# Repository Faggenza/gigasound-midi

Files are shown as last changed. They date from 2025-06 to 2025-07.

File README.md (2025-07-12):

# Gigasound MIDI Polyphonic Keyboard

A USB-connected MPE MIDI keyboard using piezoresistive sensors for expressive, pressure-sensitive input, built around the STM32F401 microcontroller.

Case

## Source Tree

```
├── sprite/     # Assets in aseprite format
├── assets_src/ # Assets in bitmap format 
├── convert_asset.py # Asset convertion tool
├── emulator/
│   ├── emulator.h
│   └── Makefile
├── gigasound-hw/ # PCB KiCad files
├── include/
│   ├── adc.h
│   ├── assets.h
│   ├── bootloader.h
│   ├── calibrate.h
│   ├── config.h
│   ├── eeprom.h
│   ├── init.h
│   ├── input.h
│   ├── led.h
│   ├── main.h
│   ├── midi.h
│   ├── scale.h
│   ├── ssd1306.h
│   ├── stm32f4xx_it.h
│   ├── tusb_config.h
│   ├── uart.h
│   └── ui/
├── lib
│   └── gigagl # embedded graphics library
├── platformio.ini 
└── src/
    ├── adc.c
    ├── assets
    ├── calibrate.c
    ├── config.c
    ├── eeprom.c
    ├── init.c
    ├── input.c
    ├── led.c
    ├── main.c
    ├── midi.c
    ├── scale.c
    ├── stm32f4xx_hal_msp.c
    ├── stm32f4xx_it.c
    ├── uart.c
    ├── ui/               
    └── usb_descriptors.c
```

## References

MCU: [STM32F0401RE](https://www.st.com/resource/en/datasheet/stm32f401re.pdf)

Nucleo: [Schematic](https://www.st.com/resource/en/schematic_pack/mb1136-default-c04_schematic.pdf)

Piezoresistive sensor: [datasheet](https://cdn2.hubspot.net/hubfs/3899023/Interlinkelectronics%20November2017/Docs/Datasheet_FSR.pdf)

MIDI: [docs](https://drive.google.com/file/d/1QGjiK2QPPbii8YmES3vDEZlP63OGLiKr/view)

## Testing

[MPE Monitor](https://studiocode.dev/mpe-monitor/)

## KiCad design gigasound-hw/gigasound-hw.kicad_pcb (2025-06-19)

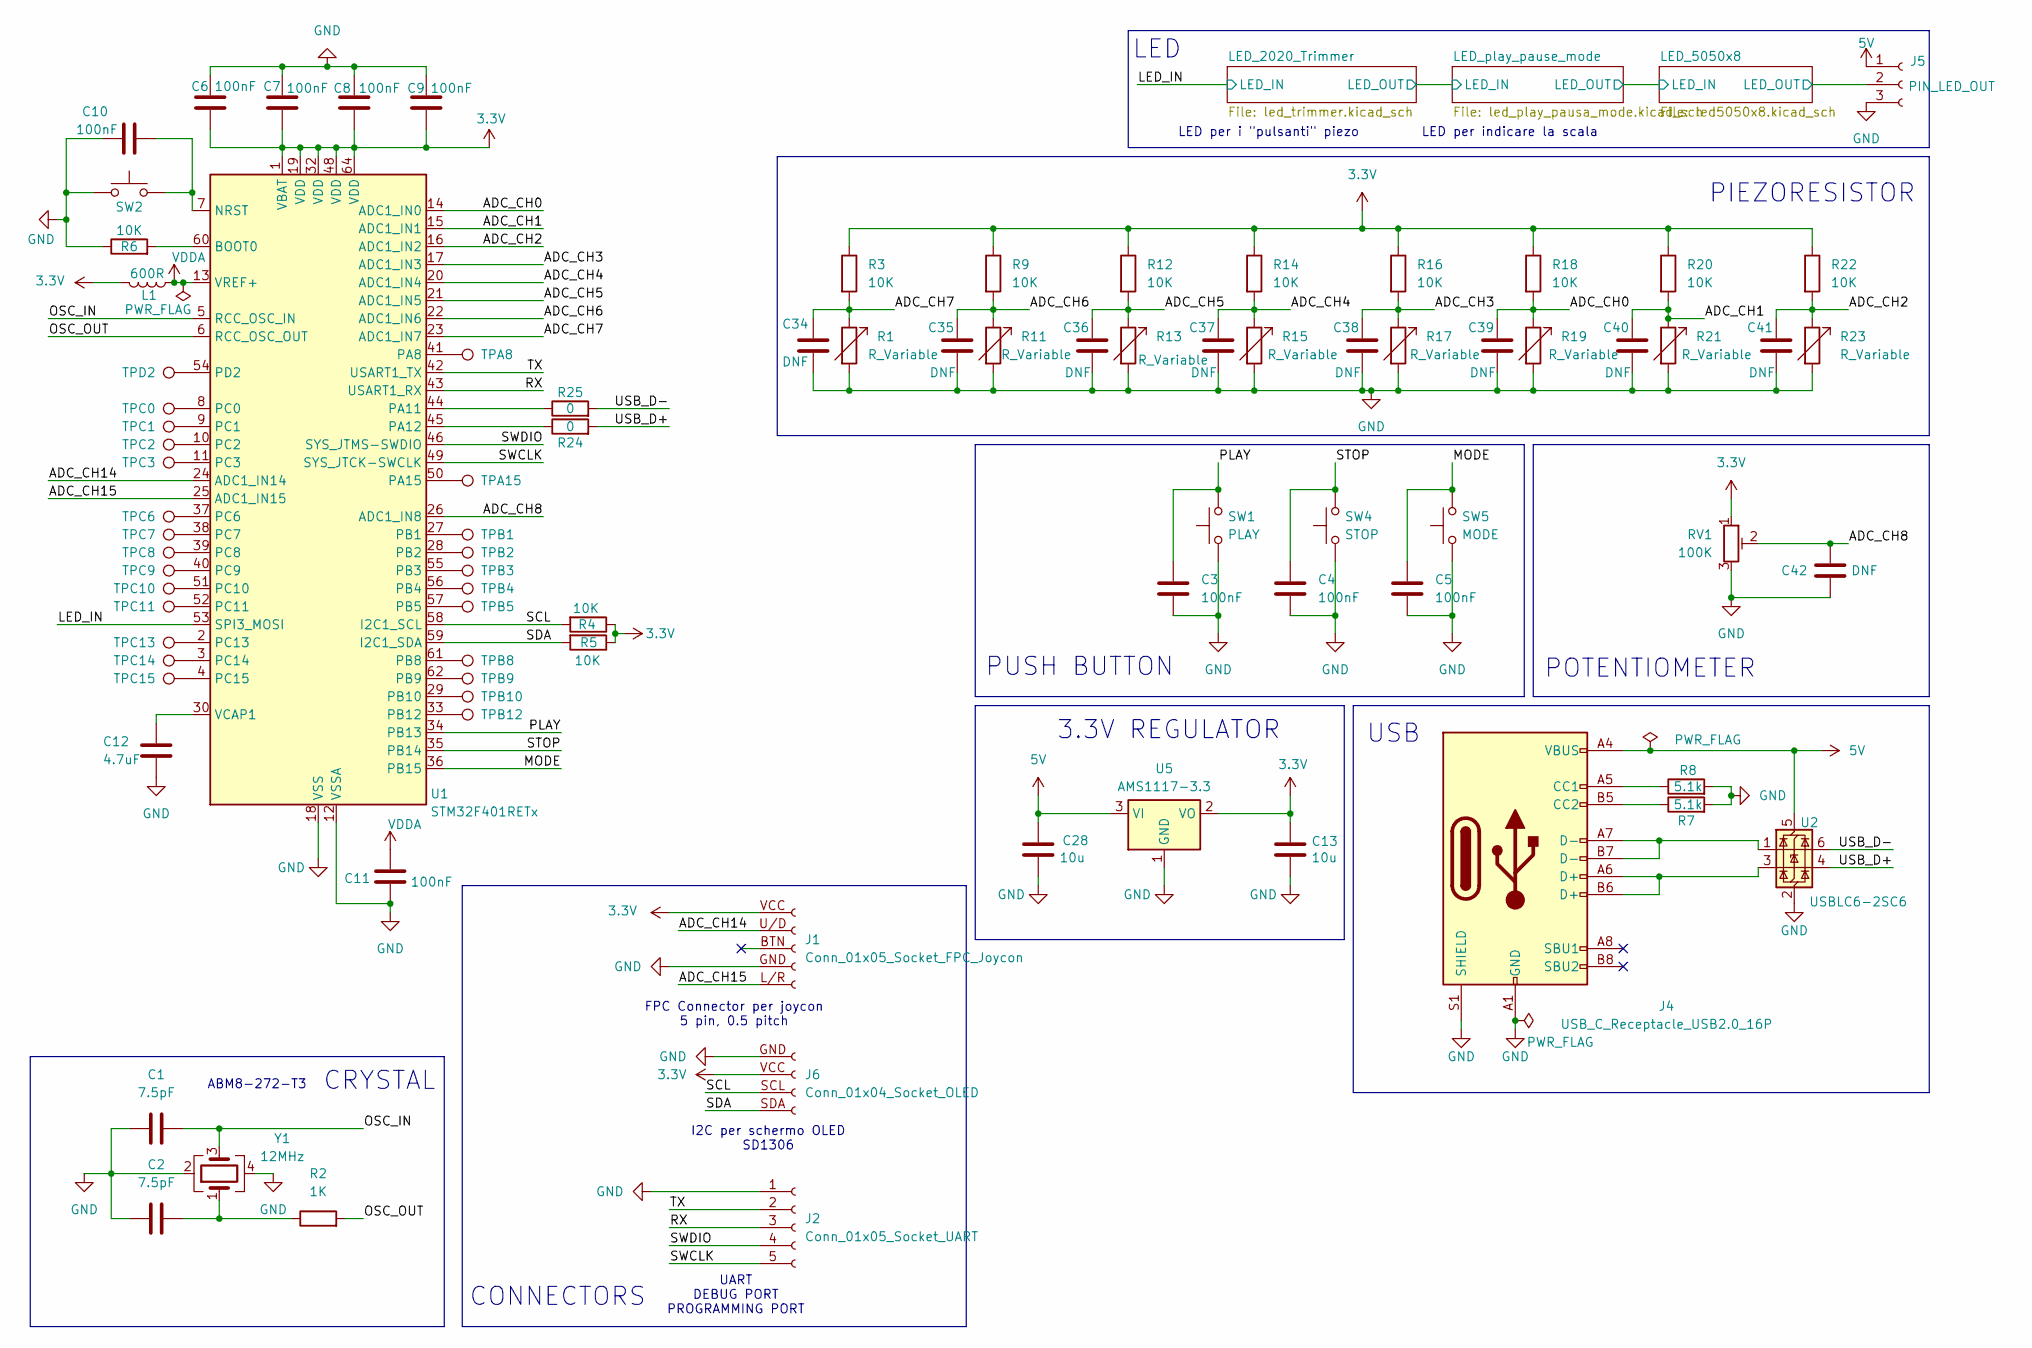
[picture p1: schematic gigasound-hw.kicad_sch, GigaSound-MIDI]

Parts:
C1, C2: 7.5pF; C_0402_1005Metric_Pad0.74x0.62mm_HandSolder
C3, C4, C5, C6, C7, C8, C9, C10, C11: 100nF; C_0402_1005Metric_Pad0.74x0.62mm_HandSolder
C12: 4.7uF; C_0805_2012Metric_Pad1.18x1.45mm_HandSolder
C13, C28: 10u; C_0805_2012Metric_Pad1.18x1.45mm_HandSolder
C34, C35, C36, C37, C38, C39, C40, C41, C42: DNF; C_0402_1005Metric_Pad0.74x0.62mm_HandSolder
J1: Conn_01x05_Socket_FPC_Joycon; Joycon-FPC-1x05-P0.5mm
J2: Conn_01x05_Socket_UART; PinHeader_1x05_P2.54mm_Vertical
J4: USB_C_Receptacle_USB2.0_16P; USB_C_Receptacle_G-Switch_GT-USB-7010ASV
J5: PIN_LED_OUT; PinHeader_1x03_P2.54mm_Vertical
J6: Conn_01x04_Socket_OLED; PinSocket_1x04_P2.54mm_Vertical_OLED_0.96inch
L1: 600R; L_0201_0603Metric_Pad0.64x0.40mm_HandSolder
R1, R11, R13, R15, R17, R19, R21, R23: R_Variable; FSR402
R2: 1K; R_0402_1005Metric_Pad0.72x0.64mm_HandSolder
R3, R4, R5, R6, R9, R12, R14, R16, R18, R20, R22: 10K; R_0402_1005Metric_Pad0.72x0.64mm_HandSolder
R7, R8: 5.1k; R_0402_1005Metric_Pad0.72x0.64mm_HandSolder
R24, R25: 0; R_0402_1005Metric_Pad0.72x0.64mm_HandSolder
RV1: 100K; Potentiometer_Alps_RK09K_Single_Vertical
SW1: PLAY; SW_SPST_TL3342
SW2: Reset; SW_Push_SPST_NO_Alps_SKRK
SW4: STOP; SW_SPST_TL3342
SW5: MODE; SW_SPST_TL3342
TPA8, TPA15: TestPoint_Pad_D1.0mm
TPB1, TPB2, TPB3, TPB4, TPB5, TPB8, TPB9, TPB10, TPB12: TestPoint_Pad_D1.0mm
TPC0, TPC1, TPC2, TPC3, TPC6, TPC7, TPC8, TPC9, TPC10, TPC11, TPC13, TPC14, TPC15: TestPoint_Pad_D1.0mm
TPD2: TestPoint_Pad_D1.0mm
U1: STM32F401RETx; LQFP-64_10x10mm_P0.5mm
U2: USBLC6-2SC6; SOT-23-6
U5: AMS1117-3.3; SOT-223-3_TabPin2
Y1: 12MHz; Crystal_SMD_3225-4Pin_3.2x2.5mm

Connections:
3.3V: C6.2, C7.2, C8.2, C9.2, C13.1, J1.VCC, J6.VCC, L1.2, R3.1, R4.1, R5.1, R9.1, R12.1, R14.1, R16.1, R18.1, R20.1, R22.1, RV1.1, U1.1 (VBAT), U1.19 (VDD), U1.32 (VDD), U1.48 (VDD), U1.64 (VDD), U5.2 (VO)
5V: C28.1, J4.A4 (VBUS), J4.A9 (VBUS), J4.B4 (VBUS), J4.B9 (VBUS), J5.1, U2.5 (VBUS), U5.3 (VI); also elsewhere on the board
/ADC_CH0: C34.2, R1.1, R3.2, U1.23 (ADC1_IN7)
/ADC_CH1: C35.2, R9.2, R11.1, U1.22 (ADC1_IN6)
/ADC_CH2: C36.2, R12.2, R13.1, U1.21 (ADC1_IN5)
/ADC_CH3: C37.2, R14.2, R15.1, U1.20 (ADC1_IN4)
/ADC_CH4: C38.2, R16.2, R17.1, U1.17 (ADC1_IN3)
/ADC_CH5: C39.2, R18.2, R19.1, U1.14 (ADC1_IN0)
/ADC_CH6: C40.2, R20.2, R21.1, U1.15 (ADC1_IN1)
/ADC_CH7: C41.2, R22.2, R23.1, U1.16 (ADC1_IN2)
/ADC_CH8: C42.2, RV1.2, U1.26 (ADC1_IN8)
/ADC_CH14: J1.U/D, U1.24 (ADC1_IN14)
/ADC_CH15: J1.L/R, U1.25 (ADC1_IN15)
/LED_5050x8/LED_OUT: J5.2; also elsewhere on the board
/LED_IN: U1.53 (SPI3_MOSI); also elsewhere on the board
/MODE: C5.1, SW5.2, U1.36 (PB15)
/OSC_IN: C1.2, U1.5 (RCC_OSC_IN), Y1.3
/OSC_OUT: R2.2, U1.6 (RCC_OSC_OUT)
/PLAY: C3.1, SW1.2, U1.34 (PB13)
/RX: J2.3 (RX), U1.43 (USART1_RX)
/SCL: J6.SCL, R5.2, U1.58 (I2C1_SCL)
/SDA: J6.SDA, R4.2, U1.59 (I2C1_SDA)
/STOP: C4.1, SW4.2, U1.35 (PB14)
/SWCLK: J2.5 (SWCLK), U1.49 (SYS_JTCK-SWCLK)
/SWDIO: J2.4 (SWDIO), U1.46 (SYS_JTMS-SWDIO)
/TX: J2.2 (TX), U1.42 (USART1_TX)
/USB_D+: R24.2, U2.4 (I/O2)
/USB_D-: R25.2, U2.6 (I/O1)
GND: C1.1, C2.1, C3.2, C4.2, C5.2, C6.1, C7.1, C8.1, C9.1, C10.1, C11.2, C12.1, C13.2, C28.2, C34.1, C35.1, C36.1, C37.1, C38.1, C39.1, C40.1, C41.1, C42.1, J1.GND, J2.1 (GND), J4.A1 (GND), J4.A12 (GND), J4.B1 (GND), J4.B12 (GND), J4.S1 (SHIELD), J5.3, J6.GND, R1.2, R6.1, R7.2, R8.2, R11.2, R13.2, R15.2, R17.2, R19.2, R21.2, R23.2, RV1.3, SW1.1, SW2.1, SW4.1, SW5.1, U1.12 (VSSA), U1.18 (VSS), U1.31 (VSS), U1.47 (VSS), U1.63 (VSS), U2.2 (GND), U5.1 (GND), Y1.2, Y1.4; also elsewhere on the board
unnamed: C2.2, R2.1, Y1.1
unnamed: J4.A5 (CC1), R8.1
unnamed: J4.B5 (CC2), R7.1
unnamed: J4.A6 (D+), J4.B6 (D+), U2.3 (I/O2)
unnamed: J4.A7 (D-), J4.B7 (D-), U2.1 (I/O1)
unnamed: R6.2, U1.60 (BOOT0)
unnamed: C10.2, SW2.2, U1.7 (NRST)
unnamed: TPA8.1, U1.41 (PA8)
unnamed: R25.1, U1.44 (PA11)
unnamed: R24.1, U1.45 (PA12)
unnamed: TPA15.1, U1.50 (PA15)
unnamed: TPB1.1, U1.27 (PB1)
unnamed: TPB2.1, U1.28 (PB2)
unnamed: TPB3.1, U1.55 (PB3)
unnamed: TPB4.1, U1.56 (PB4)
unnamed: TPB5.1, U1.57 (PB5)
unnamed: TPB8.1, U1.61 (PB8)
unnamed: TPB9.1, U1.62 (PB9)
unnamed: TPB10.1, U1.29 (PB10)
unnamed: TPB12.1, U1.33 (PB12)
unnamed: TPC0.1, U1.8 (PC0)
unnamed: TPC1.1, U1.9 (PC1)
unnamed: TPC2.1, U1.10 (PC2)
unnamed: TPC3.1, U1.11 (PC3)
unnamed: TPC6.1, U1.37 (PC6)
unnamed: TPC7.1, U1.38 (PC7)
unnamed: TPC8.1, U1.39 (PC8)
unnamed: TPC9.1, U1.40 (PC9)
unnamed: TPC10.1, U1.51 (PC10)
unnamed: TPC11.1, U1.52 (PC11)
unnamed: TPC13.1, U1.2 (PC13)
unnamed: TPC14.1, U1.3 (PC14)
unnamed: TPC15.1, U1.4 (PC15)
unnamed: TPD2.1, U1.54 (PD2)
unnamed: C12.2, U1.30 (VCAP1)
VDDA: C11.1, L1.1, U1.13 (VREF+)

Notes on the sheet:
LED per i "pulsanti" piezo
USB
FPC Connector per joycon 5 pin, 0.5 pitch
POTENTIOMETER
CONNECTORS
3.3V REGULATOR
I2C per schermo OLED SD1306
LED per indicare la scala
PIEZORESISTOR
LED
UART DEBUG PORT PROGRAMMING PORT
ABM8-272-T3
PUSH BUTTON
CRYSTAL

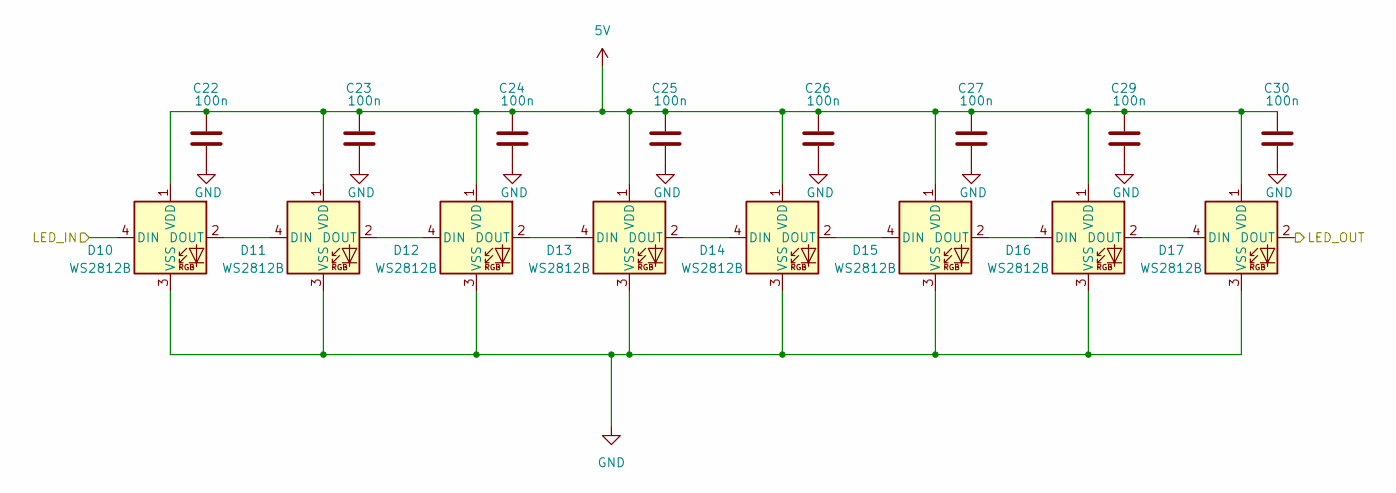
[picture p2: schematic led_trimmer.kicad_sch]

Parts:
C22, C23, C24, C25, C26, C27, C29, C30: 100n; C_0402_1005Metric_Pad0.74x0.62mm_HandSolder
D10, D11, D12, D13, D14, D15, D16, D17: WS2812B; LED_WS2812B-2020_PLCC4_2.0x2.0mm

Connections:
5V: C22.1, C23.1, C24.1, C25.1, C26.1, C27.1, C29.1, C30.1, D10.1 (VDD), D11.1 (VDD), D12.1 (VDD), D13.1 (VDD), D14.1 (VDD), D15.1 (VDD), D16.1 (VDD), D17.1 (VDD); also elsewhere on the board
/LED_2020_Trimmer/LED_OUT: D17.2 (DOUT); also elsewhere on the board
/LED_IN: D10.4 (DIN); also elsewhere on the board
GND: C22.2, C23.2, C24.2, C25.2, C26.2, C27.2, C29.2, C30.2, D10.3 (VSS), D11.3 (VSS), D12.3 (VSS), D13.3 (VSS), D14.3 (VSS), D15.3 (VSS), D16.3 (VSS), D17.3 (VSS); also elsewhere on the board
unnamed: D10.2 (DOUT), D11.4 (DIN)
unnamed: D11.2 (DOUT), D12.4 (DIN)
unnamed: D12.2 (DOUT), D13.4 (DIN)
unnamed: D13.2 (DOUT), D14.4 (DIN)
unnamed: D14.2 (DOUT), D15.4 (DIN)
unnamed: D15.2 (DOUT), D16.4 (DIN)
unnamed: D16.2 (DOUT), D17.4 (DIN)

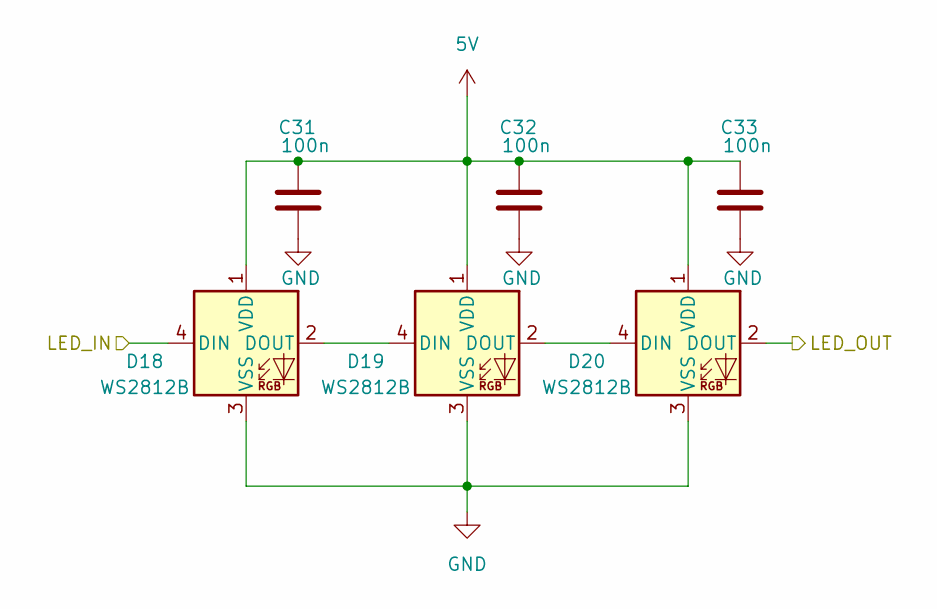
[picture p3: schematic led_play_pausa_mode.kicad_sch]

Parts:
C31, C32, C33: 100n; C_0402_1005Metric_Pad0.74x0.62mm_HandSolder
D18, D19, D20: WS2812B; LED_WS2812B-2020_PLCC4_2.0x2.0mm

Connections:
5V: C31.1, C32.1, C33.1, D18.1 (VDD), D19.1 (VDD), D20.1 (VDD); also elsewhere on the board
/LED_2020_Trimmer/LED_OUT: D18.4 (DIN); also elsewhere on the board
/LED_5050x8/LED_IN: D20.2 (DOUT); also elsewhere on the board
GND: C31.2, C32.2, C33.2, D18.3 (VSS), D19.3 (VSS), D20.3 (VSS); also elsewhere on the board
unnamed: D18.2 (DOUT), D19.4 (DIN)
unnamed: D19.2 (DOUT), D20.4 (DIN)

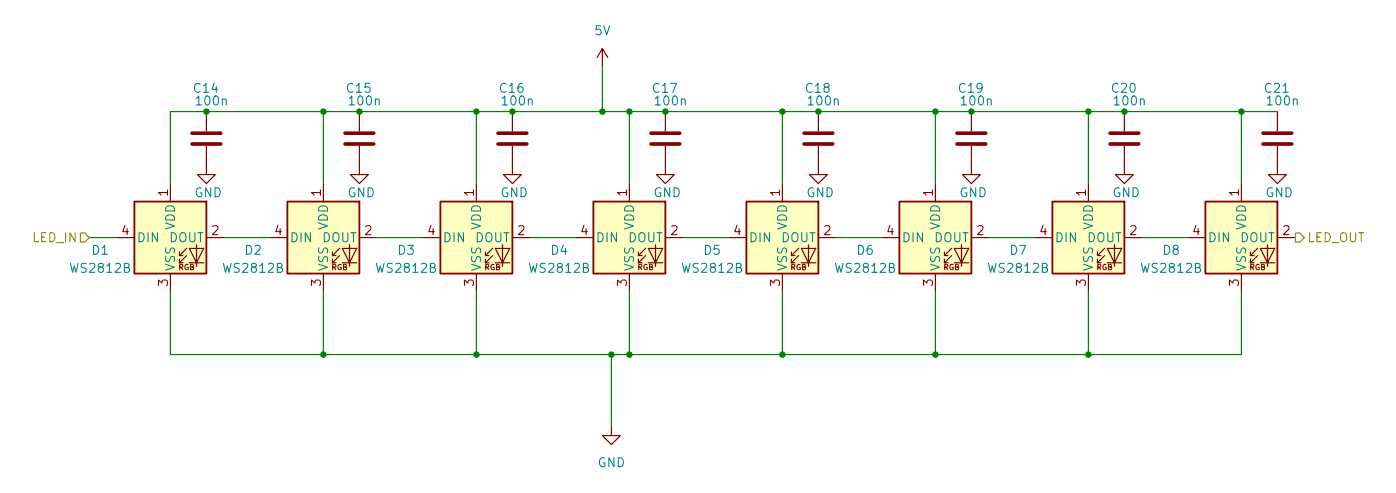
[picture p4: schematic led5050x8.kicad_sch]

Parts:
C14, C15, C16, C17, C18, C19, C20, C21: 100n; C_0402_1005Metric_Pad0.74x0.62mm_HandSolder
D1, D2, D3, D4, D5, D6, D7, D8: WS2812B; LED_WS2812B_PLCC4_5.0x5.0mm_P3.2mm

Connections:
5V: C14.1, C15.1, C16.1, C17.1, C18.1, C19.1, C20.1, C21.1, D1.1 (VDD), D2.1 (VDD), D3.1 (VDD), D4.1 (VDD), D5.1 (VDD), D6.1 (VDD), D7.1 (VDD), D8.1 (VDD); also elsewhere on the board
/LED_5050x8/LED_IN: D1.4 (DIN); also elsewhere on the board
/LED_5050x8/LED_OUT: D8.2 (DOUT); also elsewhere on the board
GND: C14.2, C15.2, C16.2, C17.2, C18.2, C19.2, C20.2, C21.2, D1.3 (VSS), D2.3 (VSS), D3.3 (VSS), D4.3 (VSS), D5.3 (VSS), D6.3 (VSS), D7.3 (VSS), D8.3 (VSS); also elsewhere on the board
unnamed: D1.2 (DOUT), D2.4 (DIN)
unnamed: D2.2 (DOUT), D3.4 (DIN)
unnamed: D3.2 (DOUT), D4.4 (DIN)
unnamed: D4.2 (DOUT), D5.4 (DIN)
unnamed: D5.2 (DOUT), D6.4 (DIN)
unnamed: D6.2 (DOUT), D7.4 (DIN)
unnamed: D7.2 (DOUT), D8.4 (DIN)

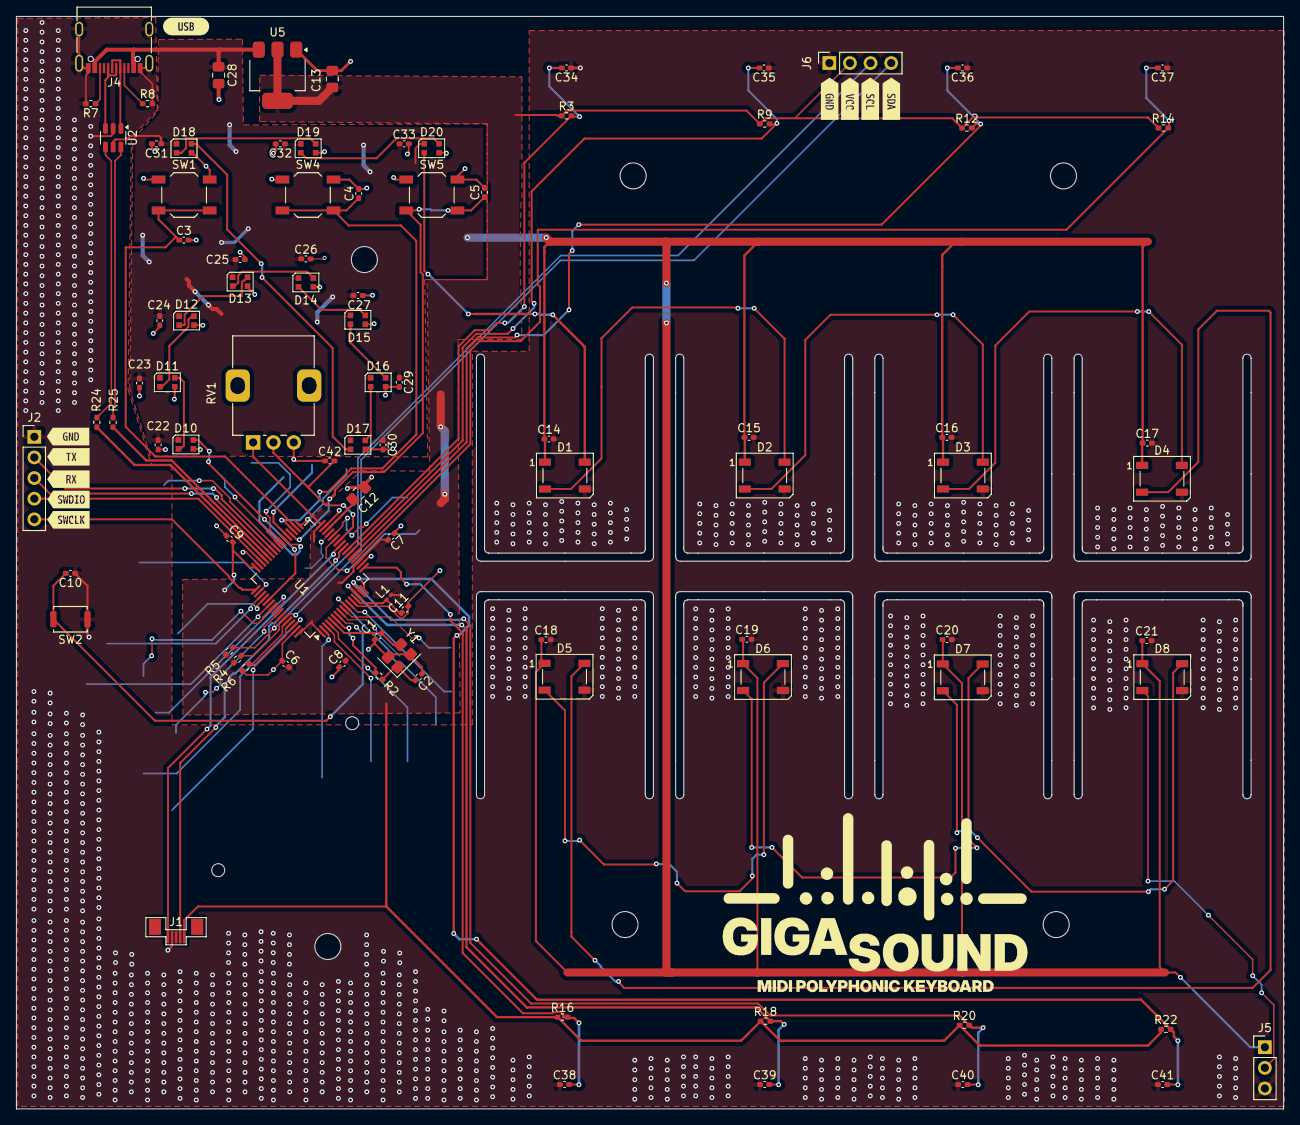
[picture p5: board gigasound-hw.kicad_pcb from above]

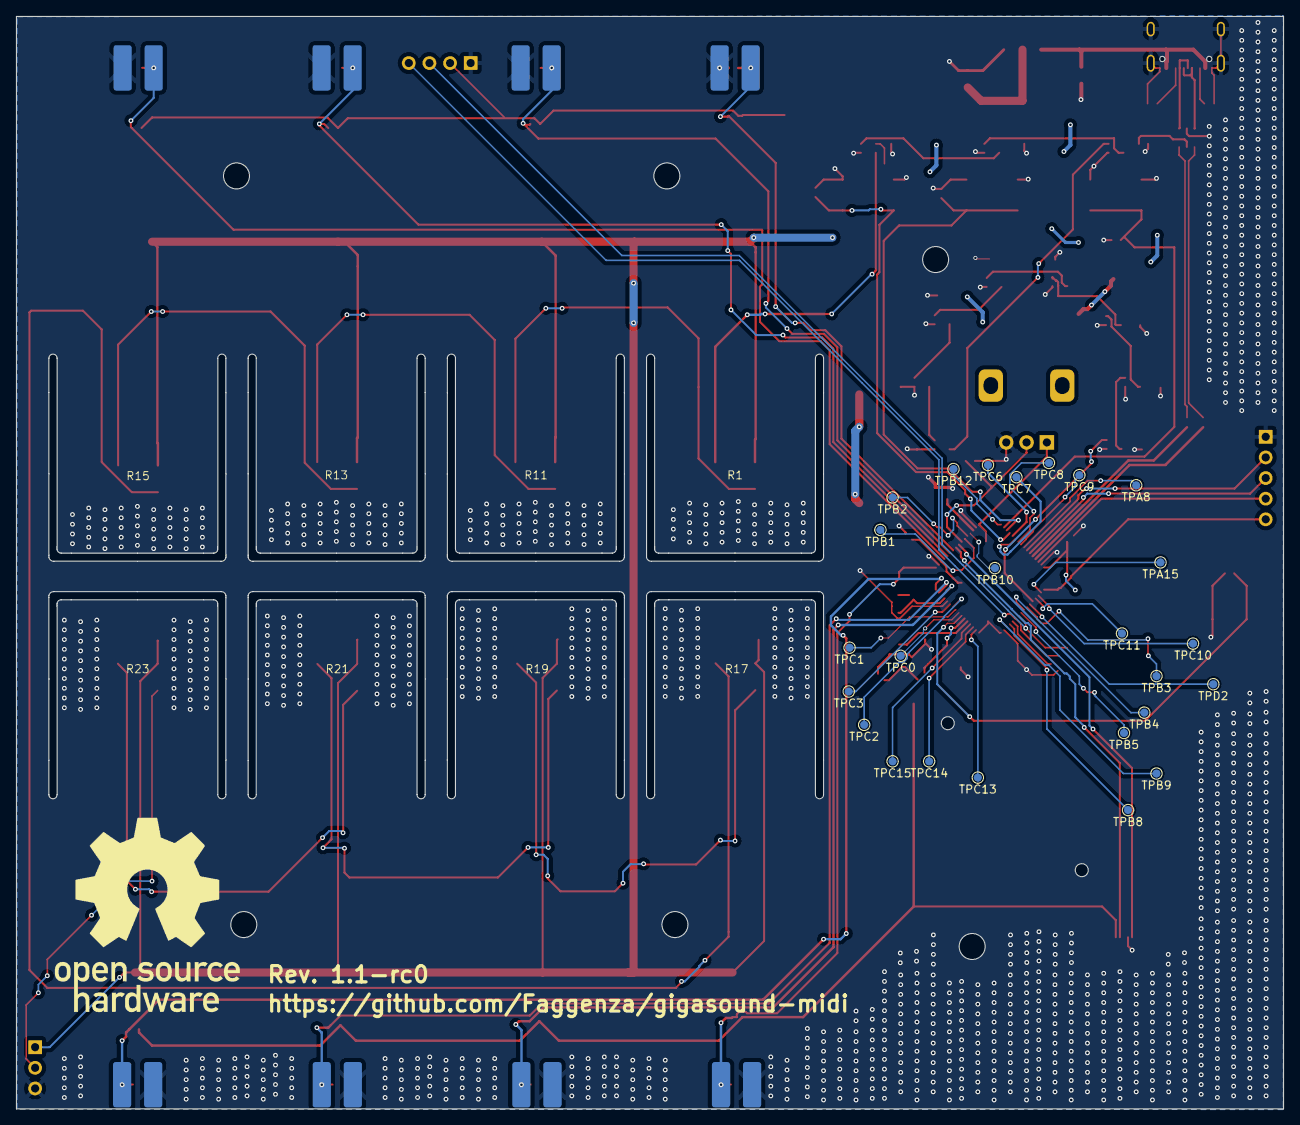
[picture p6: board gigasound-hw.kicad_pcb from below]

Board: 2 copper layers, 156.1 x 134.5 mm, 135 parts (33 on the bottom side), 83 nets.

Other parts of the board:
kibuzzard-682F341C, kibuzzard-682F341C#2: G***; kibuzzard-682F341C
kibuzzard-682F343C: G***; kibuzzard-682F343C
kibuzzard-682F3431: G***; kibuzzard-682F3431
kibuzzard-682F3436: G***; kibuzzard-682F3436
kibuzzard-682F3442: G***; kibuzzard-682F3442
kibuzzard-682F3456: G***; kibuzzard-682F3456
kibuzzard-68303C3B: G***; kibuzzard-68303C3B
kibuzzard-68303C17: G***; kibuzzard-68303C17
kibuzzard-68303C33: G***; kibuzzard-68303C33

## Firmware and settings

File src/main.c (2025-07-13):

#include <stdlib.h>
#include <stdio.h>
#include <math.h>
#include "led.h"
#include "midi.h"
#include "adc.h"
#include "input.h"
#include "gigagl.h"
#include "assets.h"
#include "calibrate.h"
#include "config.h"
#include "scale.h"
#include "ui/menu.h"
#include "ui/leds.h"
#include "ui/config.h"
#include "ui/home.h"

#ifdef EMULATOR
#include "emulator.h"
#else
#include "main.h"
#include "uart.h"
#include "init.h"
#include "bsp/board_api.h"
#include "bootloader.h"
#include "ssd1306.h"
#include "tusb.h"
#endif

void Error_Handler(void)
{
  __disable_irq();
#ifdef EMULATOR
  breakpoint();
#else
  asm("bkpt 0");
#endif
}

typedef enum
{
  MIDI_PLAYBACK,
  MENU_SCREEN,
  LED_SCREEN,
  CONFIG_SCREEN,
  SENSITIVITY_SCREEN,
  ABOUT_SCREEN,
  COLOR_SCREEN,
  SCALE_SCREEN,
  ADC_SCREEN,
} state_t;

state_t state = MIDI_PLAYBACK;

// Good artists copy, great artists steal -Pablo Picasso
#define MIN(x, y) (((x) < (y)) ? (x) : (y))
#define MAX(x, y) (((x) > (y)) ? (x) : (y))

uint16_t map(uint16_t x, uint16_t in_min, uint16_t in_max, uint16_t out_min, uint16_t out_max)
{
  if ((in_max - in_min) == 0)
    return 0;
  return (x - in_min) * (out_max - out_min) / (in_max - in_min) + out_min;
}

// This function must be called every time you are entering a busy loop
// It updates the input and keeps the usb connection alive
void loop_task()
{
  tud_task();
  if (adc_complete)
  {
    // adc_print_buffer();
    adc_complete = 0;
    update_axis_states();
  }
}

typedef enum
{
  NO_ANIMATION,
  BACK,
  FORWARD,
} animation_direction_t;

animation_direction_t dir = NO_ANIMATION;

framebuffer_t backbuffer = {0};

// Animate the transition from backbuffer to frontbuffer, swipe right to left
// https://easings.net/#easeOutCubic
// Array.from({length: 25}, (v,i) => Math.floor(easeOutCubic((i/25)) * 128))
uint8_t keyframes[] = {0, 23, 44, 61, 76,
                       89, 99, 107, 114, 118,
                       122, 124, 125, 126, 126, 128};

void animate_switch()
{
  switch (dir)
  {
  case NO_ANIMATION:
    memcpy(fb, &backbuffer, sizeof(framebuffer_t));
    while (fb_updating)
      loop_task();
    SSD1306_MINIMAL_transferFramebuffer();
    break;
  case BACK:
    uint8_t prev_delta = 0;
    for (uint8_t i = 0; i < sizeof(keyframes) - 2; i++)
    {
      while (fb_updating)
        loop_task();

      uint8_t delta = -((int)keyframes[sizeof(keyframes) - 3 - i] - 128);

      // Shift fwd the current fb by delta pixels
      for (uint8_t x = WIDTH - 1; x >= delta; x--)
      {
        // Copy the column
        for (uint8_t y = 0; y < (HEIGHT >> 3); y++)
        {
          (*fb)[y][x] = (*fb)[y][x - (delta - prev_delta)];
        }
      }

      prev_delta = delta;
      for (uint8_t x = 0; x < delta && x < WIDTH; x++)
      {
        // Copy the column
        for (uint8_t y = 0; y < (HEIGHT >> 3); y++)
        {
          (*fb)[y][x] = backbuffer[y][x];
        }
      }
      SSD1306_MINIMAL_transferFramebuffer();
    }
    break;
  case FORWARD:
    for (uint8_t i = 0; i < sizeof(keyframes); i++)
    {
      while (fb_updating)
        loop_task();

      uint8_t delta = keyframes[i];
      for (uint8_t x = 0; x < delta && x < WIDTH; x++)
      {
        // Copy the column
        for (uint8_t y = 0; y < HEIGHT; y++)
        {
          ggl_set_pixel(*fb, WIDTH - 1 - x, y, ggl_get_pixel(backbuffer, delta - 1 - x, y));
        }
      }
      SSD1306_MINIMAL_transferFramebuffer();
    }
    break;
  }
  ggl_clear_fb(backbuffer);
}

int main(void)
{

  HAL_Init();

  SystemClock_Config();

  MX_GPIO_Init();
  MX_DMA_Init();
  MX_I2C1_Init();
  MX_ADC1_Init();
  MX_USART1_UART_Init();
  MX_SPI3_Init();
  MX_USB_OTG_FS_PCD_Init();

  HAL_Delay(50); // Wait for inputs to stabilize
  if (is_key_down(MODE))
  {
    jump_to_bootloader();
  }

  config_init();

  SSD1306_MINIMAL_init();

  adc_init_dma();

  // Turn all LEDs off and start DMA
  clear_leds();
  HAL_SPI_Transmit_DMA(&hspi3, led_buff, LED_BUFF_N);

  // init device stack on configured roothub port
  tusb_rhport_init_t dev_init = {
      .role = TUSB_ROLE_DEVICE,
      .speed = TUSB_SPEED_AUTO};
  tusb_init(BOARD_TUD_RHPORT, &dev_init);

  if (board_init_after_tusb)
  {
    board_init_after_tusb();
  }

  midi_playback_state_t playback_state = {
      .current_knob = 0,
      .last_knob = 0,
      .stopped = false,
      .playing = false,
      .tone = DO,
      .scale = MAJOR,
      .key_pressed = {false},
      .timers = {0},
  };

  menu_state_t menu_state = {
      .old_selection = 0,
      .selected = 0,
      .animation_frame = 0,
  };

  led_state_t selected_led = {
      .color = OFF,
      .led_selected = 0,
      .list = {0},
  };

  config_state_t config_state = {
      .selected = 0,
      .animation_frame = 0,
      .old_selection = 0,
  };

  list_animation_t scale_select_state = {
      .selected = 0,
      .animation_frame = 0,
      .old_selection = 0,
  };

  // Calibrate the joystick at very first bootup
  if (config.joycon_calibration.calibrated == false)
  {
    state = SENSITIVITY_SCREEN;
  }

  while (1)
  {
    // Every time we change state, we want to clear the pressed buttons
    // To avoid handling the stame inputs multiple time
    clear_pressed();
    clear_leds();
    switch (state)
    {
    case MIDI_PLAYBACK:
      // So if we have deselected the scale, we want to select the first available one

      for (uint8_t i = 0; i < END_SCALE_LIST; i++)
      {
        if (config.scales_enabled[i])
        {
          playback_state.scale = i;
          break;
        }
      }

      ui_draw_home(backbuffer, &playback_state);
      animate_switch();

      playback_state.last_knob = 255;

      while (true)
      {
        loop_task();
        playback_state.current_knob = knob_step();
        if (playback_state.last_knob != playback_state.current_knob)
        {
          // Clear all the previous notes
          for (uint8_t i = 0; i < 8; i++)
          {
            midi_send_note_off(i, button_to_midi(playback_state.last_knob, playback_state.scale, playback_state.tone, i));
            playback_state.key_pressed[i] = false;
            playback_state.timers[i] = 0;
            set_led(i, OFF, 0.0f);
          }
          playback_state.last_knob = playback_state.current_knob;
          // Update the knob LEDs
          for (uint8_t i = 0; i < 8; i++)
          {
            set_led(i, OFF, 0.0f);
          }
          set_led(LED_KNOB_BASE + playback_state.current_knob, config.color[LED_KNOB_BASE], 1.0f);
        }

        // Calculate velocity based on two thresholds:
        uint16_t threshold_p1 = 3800;
        uint16_t threshold_p2 = 3600;

        for (uint8_t i = 0; i < 8; i++)
        {
          // Quirk for the second button that is broken
          if (i == 1)
          {
            threshold_p1 = 1000;
            threshold_p2 = 850;
          }
          else
          {
            threshold_p1 = 3800;
            threshold_p2 = 3600;
          }

          if (adc_buff[i] < threshold_p2 && playback_state.key_pressed[i] == false)
          {
            playback_state.key_pressed[i] = true;
            uint8_t note = button_to_midi(playback_state.current_knob, playback_state.scale, playback_state.tone, i);

            uint8_t velocity = 127;
            uint32_t t2 = HAL_GetTick();
            uint32_t t1 = playback_state.timers[i];
            // If t1 == 0 it means the user pressed so fast, the firmware didn't have time
            // to register t1, so we leave max velocity
            uint16_t dt = t2 - t1;
            if (t1 != 0 && dt != 0 && i != 1)
            {
              uint16_t distance = (threshold_p1 - adc_buff[i]) << 4;
              uint16_t v = distance / dt;

              velocity = MIN(map(v, 0, 200, 0, 127), 127);
            }

            midi_send_note_on(i, note, velocity);
            set_led(LED_BUTTON_BASE + i, config.color[LED_BUTTON_BASE + i], 0.1f);

            // Check if it's a black key (sharp/flat) using standard MIDI convention
            uint8_t note_in_octaves = note - playback_state.current_knob * 12;
            ggl_draw_rect_fill(*fb, strokes[note_in_octaves].x, strokes[note_in_octaves].y, strokes[note_in_octaves].inverted ? 3 : 4, 8, strokes[note_in_octaves].inverted);
          }
          else if (adc_buff[i] < threshold_p1 && playback_state.timers[i] == 0 && playback_state.key_pressed[i] == false)
          {
            playback_state.timers[i] = HAL_GetTick();
          }
          else if (adc_buff[i] >= threshold_p1 && playback_state.key_pressed[i] == true)
          {
            playback_state.key_pressed[i] = false;
            playback_state.timers[i] = 0;

            uint8_t note = button_to_midi(playback_state.current_knob, playback_state.scale, playback_state.tone, i);

            midi_send_note_off(i, note);
            set_led(LED_BUTTON_BASE + i, OFF, 0.0f);

            uint8_t note_in_octaves = note - playback_state.current_knob * 12;
            ggl_draw_rect_fill(*fb, strokes[note_in_octaves].x, strokes[note_in_octaves].y, strokes[note_in_octaves].inverted ? 3 : 4, 8, !strokes[note_in_octaves].inverted);
          }

          if (playback_state.key_pressed[i])
          {
            midi_set_channel_pressure(i, MIN((threshold_p1 - adc_buff[i]) >> 4, 127));
            set_led(LED_BUTTON_BASE + i, config.color[LED_BUTTON_BASE + i], ((4096 - adc_buff[i]) >> 4) / 500.0f);
          }
        }
        uint16_t p = map(adc_buff[ADC_AXIS_Y], config.joycon_calibration.y_max + 40, config.joycon_calibration.y_min - 40, 0, 16384);
        midi_set_pitch_bend(p);

        if (adc_buff[ADC_AXIS_X] < (config.joycon_calibration.x_max - config.joycon_calibration.x_min - 200))
        {
          uint16_t m = map(adc_buff[ADC_AXIS_X], (config.joycon_calibration.x_max - config.joycon_calibration.x_min) - 200, 0, 0, 16384);
          midi_send_modulation(m);
        }

        if (was_key_pressed(MODE))
        {
          // Clear all the previous notes
          for (uint8_t i = 0; i < 8; i++)
          {
            midi_send_note_off(i, button_to_midi(playback_state.last_knob, playback_state.scale, playback_state.tone, i));
            playback_state.key_pressed[i] = false;
            playback_state.timers[i] = 0;
          }

          for (uint8_t i = 1; i < END_SCALE_LIST; i++)
          {
            uint8_t selected = (playback_state.scale + i) % END_SCALE_LIST;
            if (config.scales_enabled[selected])
            {
              playback_state.scale = selected;
              break;
            }
          }

          while (fb_updating)
            loop_task();

          ui_draw_home(*fb, &playback_state);

          SSD1306_MINIMAL_transferFramebuffer();
          // Clear leds after drawing to screen to minimize artifacts
          for (uint8_t i = 0; i < 8; i++)
          {
            set_led(LED_BUTTON_BASE + i, OFF, 0.0f);
          }
        }

        if (was_key_pressed(RIGHT))
        {
          // Clear all the previous notes
          for (uint8_t i = 0; i < 8; i++)
          {
            midi_send_note_off(i, button_to_midi(playback_state.last_knob, playback_state.scale, playback_state.tone, i));
            playback_state.key_pressed[i] = false;
            playback_state.timers[i] = 0;
          }

          playback_state.tone = (playback_state.tone + 1) % 12;

          while (fb_updating)
            loop_task();

          ui_draw_home(*fb, &playback_state);

          SSD1306_MINIMAL_transferFramebuffer();

          // Clear leds after drawing to screen to minimize artifacts
          for (uint8_t i = 0; i < 8; i++)
          {
            set_led(LED_BUTTON_BASE + i, OFF, 0.0f);
          }
        }

        if (was_key_pressed(PLAY))
        {
          playback_state.playing = !playback_state.playing;
          set_led(LED_PLAY, playback_state.playing ? config.color[LED_PLAY] : OFF, 1.0f);
        }
        if (was_key_pressed(STOP))
        {
          playback_state.stopped = !playback_state.stopped;
          set_led(LED_STOP, playback_state.stopped ? config.color[LED_STOP] : OFF, 1.0f);
        }
        if (was_key_pressed(JOYC))
        {
          state = MENU_SCREEN;
          dir = FORWARD;
          break;
        }
        if (!fb_updating)
        {
          SSD1306_MINIMAL_transferFramebuffer();
        }
      }

      break;
    case MENU_SCREEN:
      ui_draw_menu(backbuffer, &menu_state);
      animate_switch();
      while (1)
      {
        loop_task();
        if (was_key_pressed(MODE) || was_key_pressed(LEFT) || was_key_pressed(JOYC))
        {
          config_save_to_flash();
          state = MIDI_PLAYBACK;
          dir = BACK;
          break;
        }
        if (animate_list(&menu_state, 4))
        {
          for (size_t i = 0; i < 6; i++)
          {
            while (fb_updating)
              loop_task();
            ui_draw_menu(*fb, &menu_state);
            SSD1306_MINIMAL_transferFramebuffer();
          }
        }
        else if (was_key_pressed(RIGHT))
        {
          dir = FORWARD;
          state_t menu_states[] = {LED_SCREEN, CONFIG_SCREEN, SENSITIVITY_SCREEN, ABOUT_SCREEN};
          state = menu_states[menu_state.selected];
          dir = FORWARD;
          break;
        }
      }
      break;
    case LED_SCREEN:
      ggl_draw_text(backbuffer, 25, 16, "Click any axis", font_data, 0);
      ggl_draw_text(backbuffer, 25, 30, "to select LED", font_data, 0);
      animate_switch();
      uint8_t current_knob = knob_step();
      uint8_t last_knob = current_knob;
      float intensity = 0.1f;
      while (1)
      {
        loop_task();
        if (was_key_pressed(LEFT))
        {
          state = MENU_SCREEN;
          dir = BACK;
          break;
        }

        // Pulse all LEDs
        for (uint8_t i = 0; i < 8; i++)
        {
          float wave = 0.5f + 0.5f * sinf(HAL_GetTick() / 300.0f + i);
          set_led(LED_BUTTON_BASE + i, config.color[LED_BUTTON_BASE + i], wave * intensity);
        }
        for (uint8_t i = 0; i < 8; i++)
        {
          float wave = 0.5f + 0.5f * sinf(HAL_GetTick() / 300.0f + i + 8);
          set_led(LED_KNOB_BASE + i, config.color[LED_KNOB_BASE], wave * intensity);
        }
        set_led(LED_PLAY, config.color[LED_PLAY], 0.2f + 0.8f * sinf(HAL_GetTick() / 500.0f));
        set_led(LED_STOP, config.color[LED_STOP], 0.2f + 0.8f * sinf(HAL_GetTick() / 500.0f + 1));
        set_led(LED_MODE, config.color[LED_MODE], 0.2f + 0.8f * sinf(HAL_GetTick() / 500.0f + 2));

        uint16_t threshold = 3600;

        for (uint8_t i = 0; i < 8; i++)
        {
          if (i == 1)
          {
            threshold = 1000;
          }
          else
          {
            threshold = 3000;
          }

          if (adc_buff[i] < threshold)
          {
            selected_led.led_selected = LED_BUTTON_BASE + i;
            selected_led.color = config.color[selected_led.led_selected];
            selected_led.list = (list_animation_t){0};
            state = COLOR_SCREEN;
            dir = FORWARD;
            goto led_screen_exit;
          }
        }

        if ((current_knob = knob_step()) != last_knob)
        {
          last_knob = current_knob;
          selected_led.led_selected = LED_KNOB_BASE;
          selected_led.color = config.color[selected_led.led_selected];
          selected_led.list = (list_animation_t){0};
          state = COLOR_SCREEN;
          dir = FORWARD;
          break;
        }

        in_key_t keys_to_check[] = {PLAY, STOP, MODE};
        uint8_t keys_leds[] = {LED_PLAY, LED_STOP, LED_MODE};
        for (size_t i = 0; i < sizeof(keys_to_check) / sizeof(keys_to_check[0]); i++)
        {
          if (was_key_pressed(keys_to_check[i]))
          {
            selected_led.led_selected = keys_leds[i];
            selected_led.color = config.color[selected_led.led_selected];
            selected_led.list = (list_animation_t){};
            state = COLOR_SCREEN;
            dir = FORWARD;
            goto led_screen_exit;
          }
        }
      }
    led_screen_exit:
      break;
    case COLOR_SCREEN:
      ui_draw_leds(backbuffer, &selected_led);
      animate_switch();
      while (1)
      {
        loop_task();

        animate_list(&selected_led.list, 3);
        if (is_key_down(RIGHT))
        {
          config_modified = true;
          selected_led.color.rgb[selected_led.list.selected] += 1;
          while (fb_updating)
            loop_task();
          ui_draw_leds(*fb, &selected_led);
          SSD1306_MINIMAL_transferFramebuffer();
        }
        else if (is_key_down(LEFT))
        {
          config_modified = true;
          selected_led.color.rgb[selected_led.list.selected] -= 1;
          while (fb_updating)
            loop_task();
          ui_draw_leds(*fb, &selected_led);
          SSD1306_MINIMAL_transferFramebuffer();
        }
        if (selected_led.led_selected == LED_KNOB_BASE)
        {
          for (size_t i = 0; i < 8; i++)
          {
            set_led(LED_KNOB_BASE + i, selected_led.color, 0.1f);
          }
        }
        else
        {
          set_led(selected_led.led_selected, selected_led.color, 0.1f);
        }
        if (was_key_pressed(STOP))
        {
          config.color[selected_led.led_selected] = selected_led.color;
          state = LED_SCREEN;
          dir = BACK;
          break;
        }
        if (!fb_updating)
        {
          ui_draw_leds(*fb, &selected_led);
          SSD1306_MINIMAL_transferFramebuffer();
        }
      }
      break;
    case CONFIG_SCREEN:
      ui_draw_config(backbuffer, &config_state);
      animate_switch();
      while (1)
      {
        loop_task();
        if (was_key_pressed(LEFT) || was_key_pressed(STOP))
        {
          state = MENU_SCREEN;
          dir = BACK;
          break;
        }

        if (animate_list(&config_state, 3))
        {
          for (size_t i = 0; i < 6; i++)
          {
            while (fb_updating)
              loop_task();
            ui_draw_config(*fb, &config_state);
            SSD1306_MINIMAL_transferFramebuffer();
          }
        }

        if (was_key_pressed(RIGHT))
        {
          switch (config_state.selected)
          {
          case CONFIG_SHOW_ADC:
            state = ADC_SCREEN;
            dir = FORWARD;
            goto exit_config_screen;
          case CONFIG_SCALE:
            state = SCALE_SCREEN;
            dir = FORWARD;
            goto exit_config_screen;
          case CONFIG_DFU:
            while (fb_updating)
              loop_task();
            ggl_clear_fb(*fb);
            ggl_draw_text(*fb, 40, 18, "DFU Mode", font_data, 0);
            SSD1306_MINIMAL_transferFramebuffer();
            while (fb_updating)
              loop_task();
            jump_to_bootloader();
            break;
          }
        }
      }
    exit_config_screen:
      break;
    case ADC_SCREEN:
      ggl_draw_text(backbuffer, 26, 8, "ADC Debugging", font_data, 0);
      animate_switch();
      while (1)
      {
        loop_task();
        if (was_key_pressed(STOP))
        {
          state = CONFIG_SCREEN;
          dir = BACK;
          break;
        }
        if (!fb_updating)
        {
          ggl_clear_fb(*fb);
          ggl_draw_text(*fb, 26, 8, "ADC Debugging", font_data, 0);
          for (uint8_t i = 0; i < 11; i++)
          {
            char buffer[16];
            snprintf(buffer, sizeof(buffer), "%4d", adc_buff[i]);
            uint8_t x = 6 + (i / 3) * 30;  // Each column starts 40 pixels apart
            uint8_t y = 20 + (i % 3) * 10; // Each row is 10 pixels apart within a column
            ggl_draw_text(*fb, x, y, buffer, font_data, 0);
          }
          SSD1306_MINIMAL_transferFramebuffer();
        }
      }
      break;
    case SCALE_SCREEN:
      ui_draw_scale_selector(backbuffer, &scale_select_state);
      animate_switch();
      while (1)
      {
        loop_task();
        if (was_key_pressed(LEFT) || was_key_pressed(STOP))
        {
          bool consistant = false;
          for (uint8_t i = 0; i < END_SCALE_LIST; i++)
          {
            if (config.scales_enabled[i])
            {
              consistant = true;
              break;
            }
          }
          // Make sure that at least the basic major scale is enabled
          // if the user happens to deselect all of them
          if (!consistant)
          {
            config.scales_enabled[MAJOR] = true;
          }
          state = CONFIG_SCREEN;
          dir = BACK;
          break;
        }

        if (animate_list(&scale_select_state, END_SCALE_LIST))
        {
          for (size_t i = 0; i < 6; i++)
          {
            while (fb_updating)
              loop_task();
            ui_draw_scale_selector(*fb, &scale_select_state);
            SSD1306_MINIMAL_transferFramebuffer();
          }
        }

        if (was_key_pressed(RIGHT))
        {
          config.scales_enabled[scale_select_state.selected] = !config.scales_enabled[scale_select_state.selected];
          config_modified = true;
          while (fb_updating)
            loop_task();
          ui_draw_scale_selector(*fb, &scale_select_state);
          SSD1306_MINIMAL_transferFramebuffer();
        }
      }
      break;
    case SENSITIVITY_SCREEN:
      ggl_draw_text(backbuffer, 30, 18, "Calibrating", font_data, 0);

      ggl_draw_text(backbuffer, 2, 30, "Press STOP when done", font_data, 0);
      animate_switch();
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

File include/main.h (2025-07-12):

/* Define to prevent recursive inclusion -------------------------------------*/
#ifndef __MAIN_H
#define __MAIN_H

/* Includes ------------------------------------------------------------------*/
#include "stm32f4xx_hal.h"

void Error_Handler(void);

#define B1_Pin GPIO_PIN_13
#define B1_GPIO_Port GPIOC
#define USART_TX_Pin GPIO_PIN_2
#define USART_TX_GPIO_Port GPIOA
#define USART_RX_Pin GPIO_PIN_3
#define USART_RX_GPIO_Port GPIOA
#define LD2_Pin GPIO_PIN_5
#define LD2_GPIO_Port GPIOA
#define TMS_Pin GPIO_PIN_13
#define TMS_GPIO_Port GPIOA
#define TCK_Pin GPIO_PIN_14
#define TCK_GPIO_Port GPIOA
#define SWO_Pin GPIO_PIN_3
#define SWO_GPIO_Port GPIOB

#define PLAY_Pin GPIO_PIN_13
#define STOP_Pin GPIO_PIN_14
#define MODE_Pin GPIO_PIN_15
#define JOYC_Pin GPIO_PIN_3

#endif /* __MAIN_H */

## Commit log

2025-04-30 try uart
    [gigasound-hw.kicad_pcb, gigasound-hw.kicad_sch]
2025-05-07 fix uart
2025-05-07 add some symbols
    [gigasound-hw.kicad_sch]
2025-05-07 progress hw schematic
    [gigasound-hw.kicad_sch]
2025-05-07 Fix adc
2025-05-07 hw: added usb, 3.3v, cleaned up
    [gigasound-hw.kicad_sch]
2025-05-14 working ws2812
    [gigasound-hw.kicad_sch]
2025-05-14 add led to sch
    [gigasound-hw.kicad_sch, led5050x8.kicad_sch, led_play_pausa_mode.kicad_sch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]
2025-05-14 ws2812 driver
2025-05-14 add led dma control
2025-05-14 add adc dma support
2025-05-14 implement dma adc
2025-05-14 fix GIGA error
    [gigasound-hw.kicad_sch]
2025-05-15 msp usb
    [gigasound-hw.kicad_sch]
2025-05-15 add footprint
    [gigasound-hw.kicad_sch, led5050x8.kicad_sch, led_play_pausa_mode.kicad_sch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]
2025-05-20 hw: footprints
    [gigasound-hw.kicad_sch]
2025-05-20 hw: initial placement
    [gigasound-hw.kicad_pcb]
2025-05-21 hw: Finished footprints
    [gigasound-hw.kicad_pcb, gigasound-hw.kicad_sch]
2025-05-21 hw: finish layout
    [gigasound-hw.kicad_pcb, gigasound-hw.kicad_sch]
2025-05-21 hw: start routing
    [gigasound-hw.kicad_pcb, gigasound-hw.kicad_sch]
2025-05-21 hw: finish routing
    [gigasound-hw.kicad_pcb]
2025-05-21 hw: add GND plane
    [freerouting.dsn, gigasound-hw.kicad_pcb, temp-freerouting.dsn]
2025-05-22 hw: added esd protection and caps
    [gigasound-hw.kicad_pcb, gigasound-hw.kicad_sch]
2025-05-22 hw: silkscreen
    [gigasound-hw.kicad_pcb]
2025-05-22 hw: fix drc errors
    [gigasound-hw.kicad_pcb]
2025-05-22 hw: gigasound logo
    [gigasound-hw.kicad_pcb]
2025-05-23 hw: add mounting holes
    [bom.csv, designators.csv, gigasound-hw.kicad_pcb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]
2025-05-23 hw: fix vias on silkscreen
    [gigasound-hw.kicad_pcb]
2025-05-23 hw: final touches
    [gigasound-hw.kicad_pcb, gigasound-hw.kicad_sch]
2025-05-28 remove production files
    [bom.csv, designators.csv, positions.csv]
2025-06-17 fix clock
    [gigasound-hw.kicad_pcb, gigasound-hw.kicad_sch]
2025-06-17 hw: fix big mistake
    [gigasound-hw.kicad_pcb, gigasound-hw.kicad_sch]
2025-06-18 fw: working display without dma
2025-06-18 fw: Buttons
2025-06-18 fw: fix dma oled
    [main.c]
2025-06-18 fw: fix oled direction
    [main.c]
2025-06-18 fw: joycon calibration
2025-06-19 fw: fix menu animation
    [config.c, main.c]
2025-06-19 hw: new pcb revision candidate
    [gigasound-hw.kicad_pcb, gigasound-hw.kicad_sch]
2025-06-19 fw: fix adc order
2025-06-19 fw: modularize adc and input
2025-06-19 fw: insert font
2025-06-19 fw: compiler is too powerful
2025-06-26 fw: fix asset importing
    [main.c]
2025-06-27 fw: all buttons
2025-06-27 fw: start led custom
2025-06-27 fw: led color screen
2025-06-28 fw: custom leds
2025-06-30 fw: squash final bugs
    [calibrate.c, config.c, emulator.h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]
2025-06-30 fw: fix led screen
    [main.c]
2025-06-30 fw: fix notes off when changed
    [main.c]
2025-07-03 fw: missing state change
    [main.c]
2025-07-12 Implemented joycon button
2025-07-12 fw: fix all warnings
    [led.h]
2025-07-13 fw: improve button debounce
2025-07-13 fw: fix pressure > 127
    [main.c]
2025-07-13 fw: add adc debug screen
2025-07-13 fw: implemented velocity
2025-07-13 fw: fix clearing leds on change
    [main.c]
2025-07-13 fw: led screen animation
